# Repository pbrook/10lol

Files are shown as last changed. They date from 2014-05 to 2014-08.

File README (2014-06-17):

10LOL display board (10mm rgb led charlieplexed display matrix)
====

Hardware designs and firmware for a modular matrix display board.

Each module consists of an LED carrier board and a driver board.

Supply voltage is 7-20V (with onboard switching regulator).
TODO: Figure out actual power requirements, and if a single regulator can power
multiple modules.

The control board 
Modules operate autonomously,  module operates autonomously, accepting data over SPI.
The modules can be programmed with unique addresses, allowing
multiple modules on a single SPI bus.

SPI communication protocol
====

Commands are 4 bytes.  The first byte identidies the command, followed by 3
bytes of argument data (d0-d2).

On power-up the board will be in disconnected state.  A disconnect command
followed by a connect command should be used to ensure the serial interface
is coherent, and the board is in the ready state.

Command 0xe1 puts the specified board into the active state (other
previously active boards return to the ready state).

Commands <0xd0 are ignored when the board is not active.

Commands are as follows:

0x00 - 0x3f: Write pixel
 Pixels numbered left-right,then top-bottom)
  d0: red
  d1: green
  d2: blue

0x80: Page flip
 Set the framebuffer page for both display and pixel writing.
 This allows double buffered updates
  d0: Unused(0)
  d1: display page number
  d2: pixel write page number

0xa0: Initialize FORTH
 Initialize and enable the FORTH interpreter.
 The forth dictionary is stored at the end of the framebuffer.
  d0: rstack size (cells)
  d1: Dictionary size (in 256-byte framebuffer pages)
  d2: Unused (0)

0xa1: FORTH source
 Send one to three bytes of FORTH source code.  Null (0) characters are ignored.
  d0: First character
  d1: Second character
  d2: Third character

0xc0: Set brightness
 Sets brightness/color ballance (stored in EEPROM)
  d0: Red brightness
  d1: Green brightness
  d2: Blue brightness

0xd0: Set board address
 Modifies the board address (stored in EEPROM).
 The board will only respond to this address if the SDA pin is pulled low.
 This allows the addresses to be set without disconnecting the board.
  d0: 0xf5
  d1: 0xf0 + high address nibble
  d2: 0xf0 + low address nibble

0xe0: Connect
 Prepares the board for other commands
  d0: 0xf0
  d1: 0xf1
  d2: 0xf2

0xe1: Board select
 Only the selected board will respond to most commands.
  d0: board address (0xff to select all boards)
  d1: Unused (0)
  d2: Unused (0)

0xff: Disconnect
 Reset serial interface.
 The connect command must be sent before any other commands.
 The data bytes on this command are optional.  However sending the full
 sequence bytes ensures that the board is preoperly aligned with the
 four byte command boundary.
  d0: 0xff
  d1: 0xff
  d2: 0xff

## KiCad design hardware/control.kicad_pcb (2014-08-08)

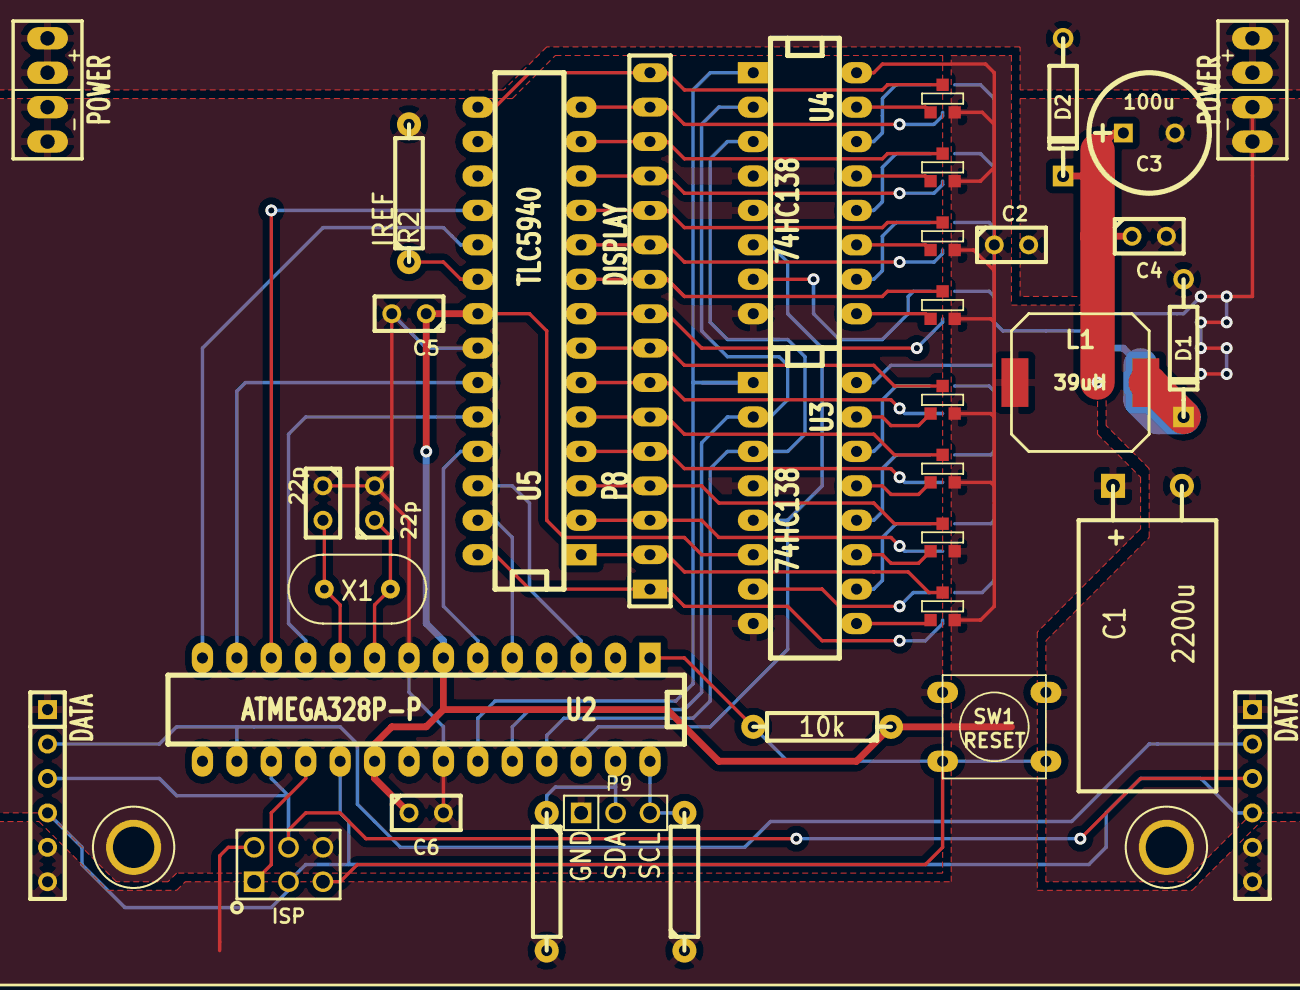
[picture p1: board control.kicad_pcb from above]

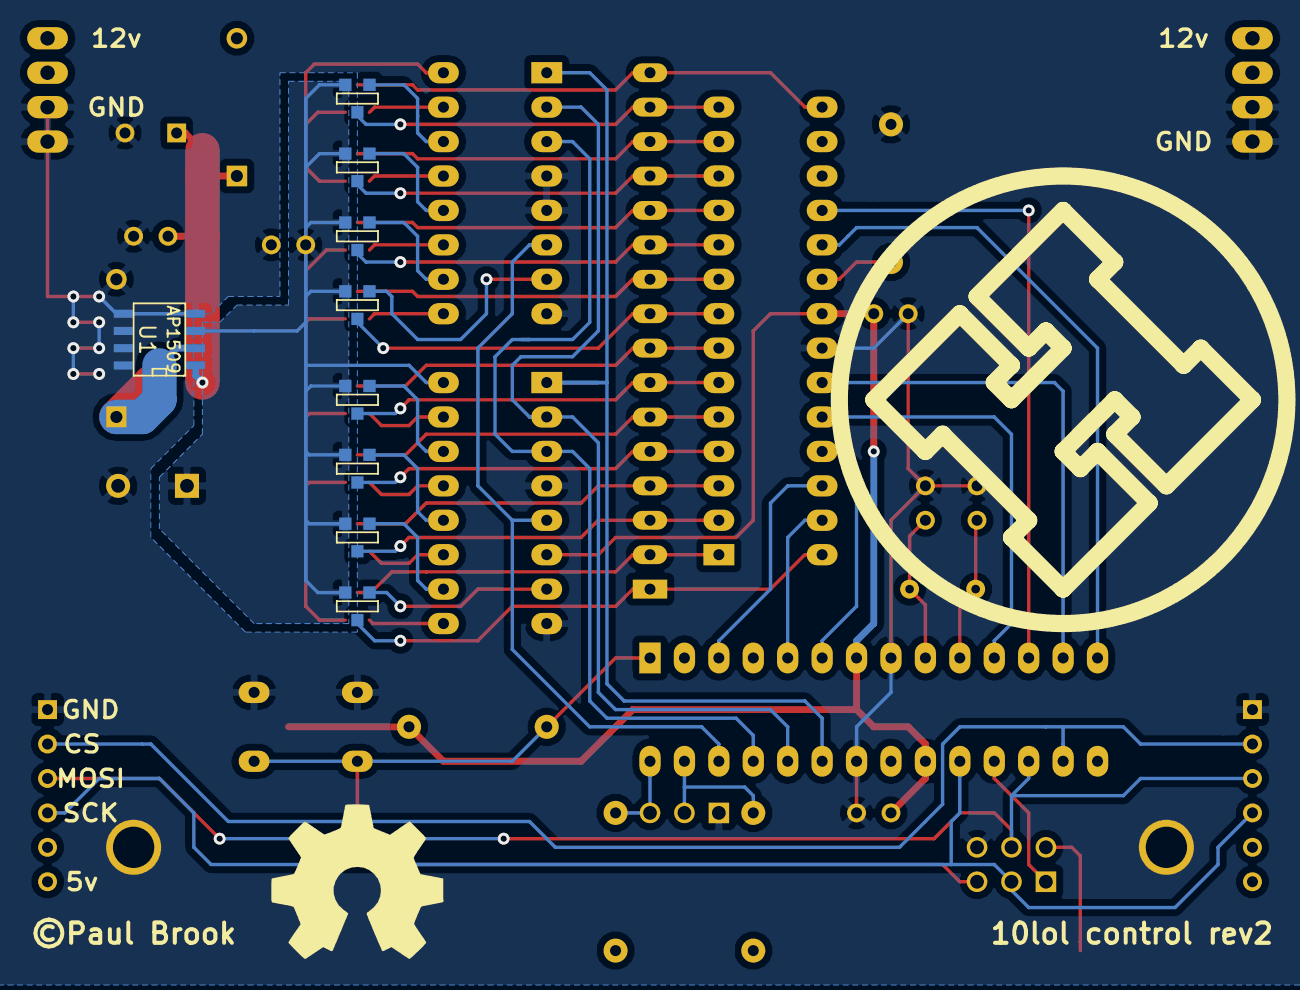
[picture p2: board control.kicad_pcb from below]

Board: 2 copper layers, 48 parts (10 on the bottom side), 58 nets.

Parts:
C1: 2200u; CPR10X20
C2, C4, C5, C6: 100n; C1
C3: 100u; C1.5V8V
C8, C9: 22p; C1
D1, D2: SR104; DO-41
HACKSPACE_LOGO: VAL**; HACKSPACE_LOGO
L1: 39uH; self_cms_we-tpc_XL
P1, P2: POWER; power2
P3, P4: DATA; SIL-6
P5: ISP; isp
P6, P7: CONN_1; HOLE3
P8: DISPLAY; SIL-16-ELL
P9: I2C; PIN_ARRAY_3X1
Q1, Q2, Q3, Q4, Q5, Q6, Q7, Q8, Q9, Q10, Q11, Q12, Q13, Q14, Q15, Q16: NX2301P; SOT23GDS_NP
R1: 10k; R4-LARGE_PADS
R2: IREF; R4-LARGE_PADS
R3: SDA; R4-LARGE_PADS
R4: SCL; R4-LARGE_PADS
SW1: RESET; SW_PUSH_SMALL
U1: AP1509; SO8E
U2: ATMEGA328P-P; DIP-28__300_ELL
U3, U4: 74HC138; DIP-16__300_ELL
U5: TLC5940; DIP-28__300_ELL
X1: 16MHz; Crystal

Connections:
/5v: C1.1, C2.1, C5.1, C6.1, L1.1, P3.5, P3.6, P4.5, P4.6, P5.2, Q1.S, Q2.S, Q3.S, Q4.S, Q5.S, Q6.S, Q7.S, Q8.S, Q9.S, Q10.S, Q11.S, Q12.S, Q13.S, Q14.S, Q15.S, Q16.S, R1.1, R3.2, R4.1, U1.3, U2.7, U2.20, U3.6, U3.16, U4.16, U5.21
/12v: C3.1, C4.1, D2.2, U1.1
/A: P8.1, Q1.D, U5.28
/A0: U2.23, U3.1, U4.1
/A1: U2.24, U3.2, U4.2
/A2: U2.25, U3.3, U4.3
/A3: U2.26, U3.5, U4.6
/Ai: Q1.G, U3.7
/B: P8.2, Q2.D, U5.1
/BLANK: U2.13, U5.23
/Bi: Q2.G, U3.9
/C: P8.3, Q3.D, U5.2
/CS: P3.2, P4.2, U2.16
/Ci: Q3.G, U3.10
/D: P8.4, Q4.D, U5.3
/DCPRG: U2.14, U5.19
/Di: Q4.G, U3.11
/E: P8.5, Q5.D, U5.4
/Ei: Q5.G, U3.12
/F: P8.6, Q6.D, U5.5
/Fi: Q6.G, U3.13
/G: P8.7, Q7.D, U5.6
/GND: C1.2, C2.2, C3.2, C4.2, C5.2, C6.2, C8.2, C9.1, D1.1, P1.1, P2.1, P3.1, P4.1, P5.6, P6.1, P7.1, P9.1, R2.2, SW1.1, U1.4, U1.5, U1.6, U1.7, U1.8, U2.8, U2.22, U3.4, U3.8, U4.4, U4.5, U4.8, U5.22
/GSCLK: U2.12, U5.18
/Gi: Q7.G, U3.14
/H: P8.8, Q8.D, U5.7
/Hi: Q8.G, U3.15
/IREF: R2.1, U5.20
/J: P8.9, Q9.D, U5.8
/Ji: Q9.G, U4.7
/K: P8.10, Q10.D, U5.9
/Ki: Q10.G, U4.9
/M: P8.11, Q11.D, U5.10
/MISO: P5.1, U2.18
/MOSI: P3.3, P4.3, P5.4, U2.17
/Mi: Q11.G, U4.10
/N: P8.12, Q12.D, U5.11
/Ni: Q12.G, U4.11
/P: P8.13, Q13.D, U5.12
/Pi: Q13.G, U4.12
/Q: P8.14, Q14.D, U5.13
/Qi: Q14.G, U4.13
/R: P8.15, Q15.D, U5.14
/RESET: P5.5, R1.2, SW1.2, U2.1
/Ri: Q15.G, U4.14
/S: P8.16, Q16.D, U5.15
/SCK: P3.4, P4.4, P5.3, U2.19
/SCL: P9.3, R4.2, U2.28
/SCLK: U2.6, U5.25
/SDA: P9.2, R3.1, U2.27
/SIN: U2.3, U5.26
/Si: Q16.G, U4.15
/VPRG: U2.5, U5.27
/XLAT: U2.11, U5.24
/out: D1.2, L1.2, U1.2
/raw: D2.1, P1.2, P2.2
unnamed: C9.2, U2.10, X1.1
unnamed: C8.1, U2.9, X1.2

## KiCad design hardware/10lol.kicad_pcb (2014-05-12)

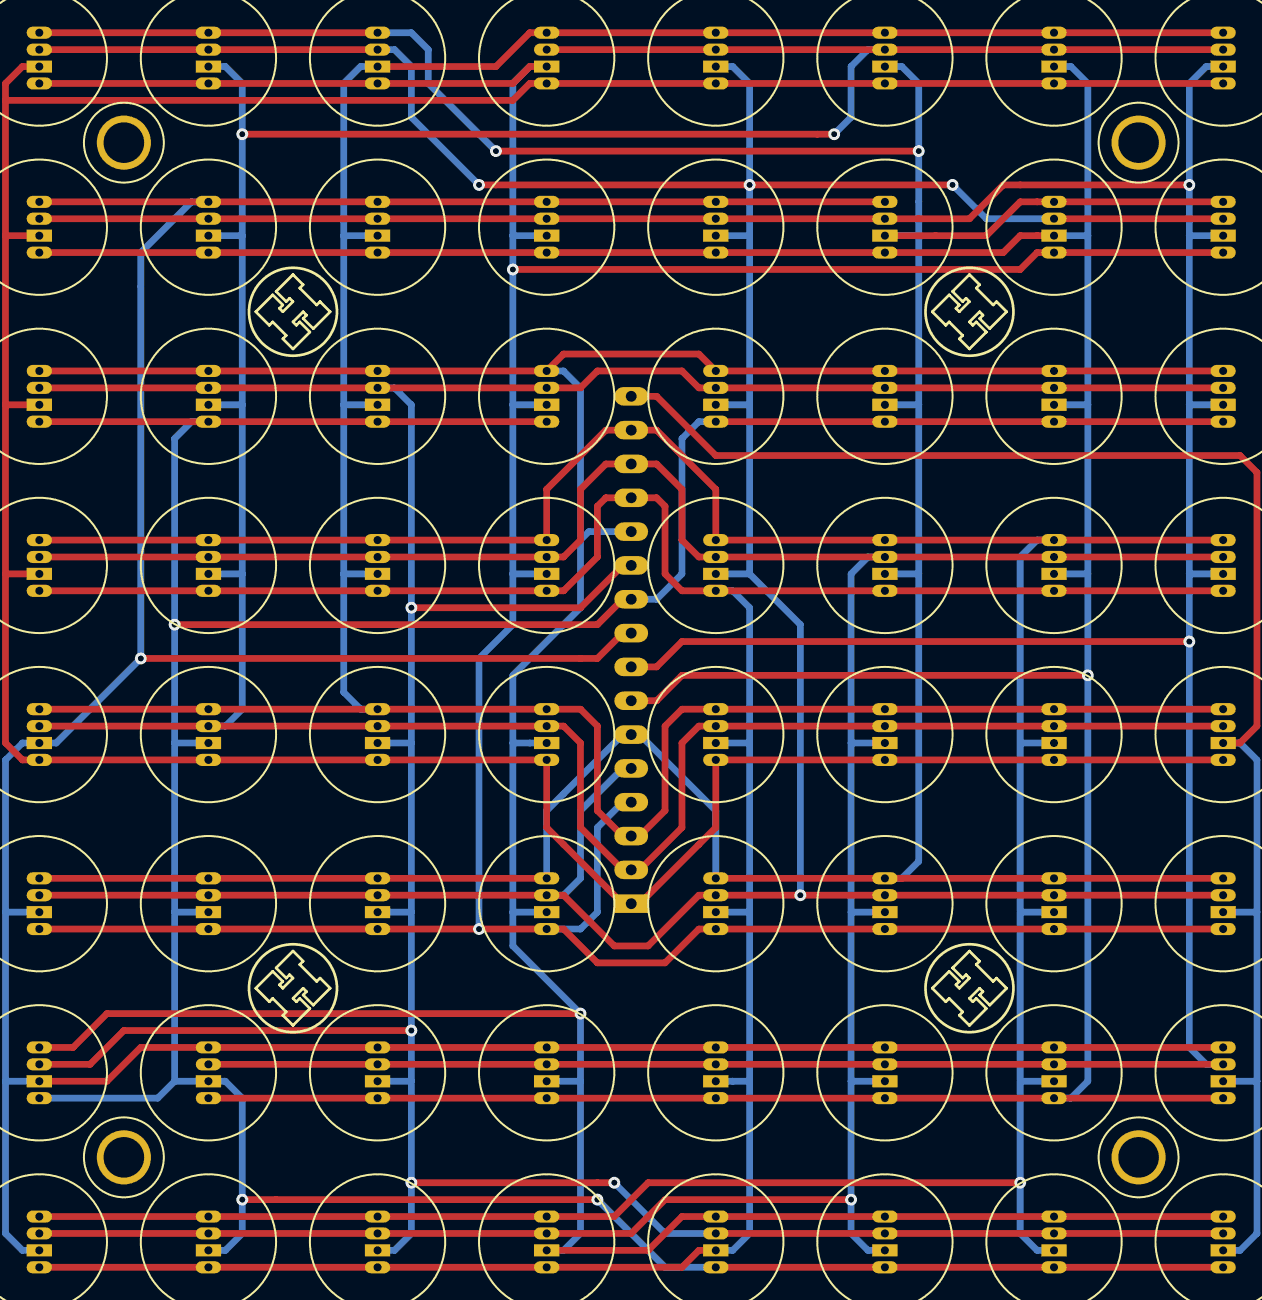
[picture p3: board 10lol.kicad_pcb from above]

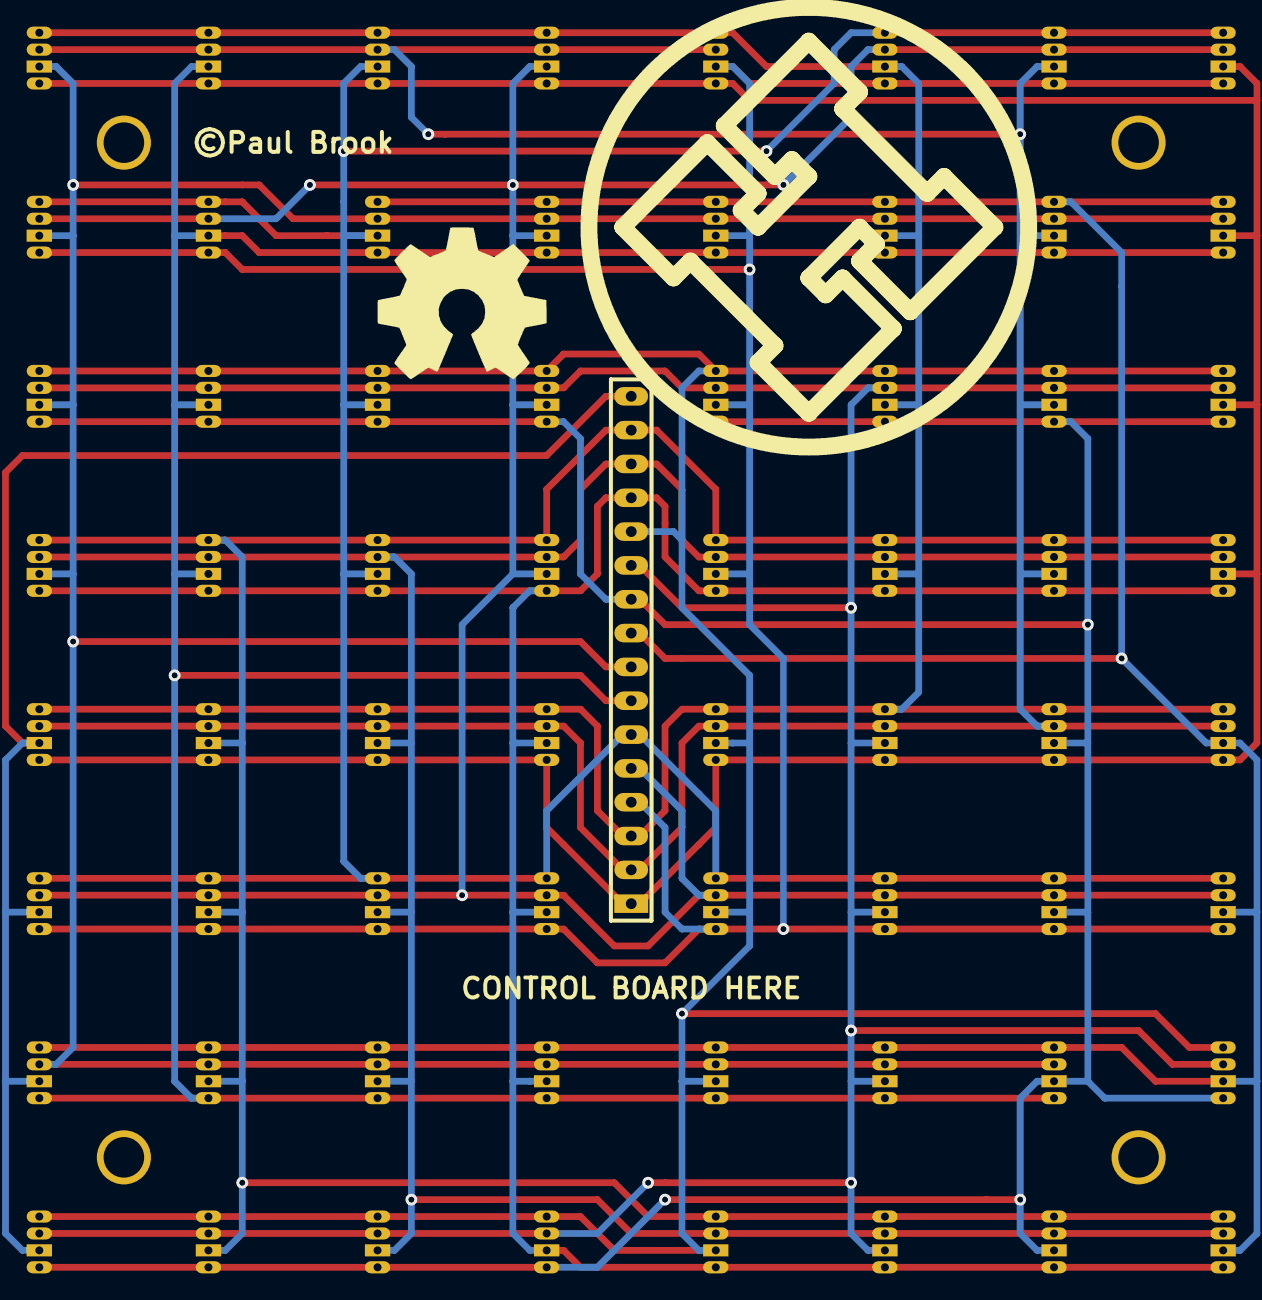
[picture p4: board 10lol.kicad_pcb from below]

Board: 2 copper layers, 74 parts (2 on the bottom side), 16 nets.

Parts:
D1, D2, D3, D4, D5, D6, D7, D8, D9, D10, D11, D12, D13, D14, D15, D16, D17, D18, D19, D20, D21, D22, D23, D24, D25, D26, D27, D28, D29, D30, D31, D32, D33, D34, D35, D36, D37, D38, D39, D40, D41, D42, D43, D44, D45, D46, D47, D48, D49, D50, D51, D52, D53, D54, D55, D56, D57, D58, D59, D60, D61, D62, D63, D64: RGBLED; RGB_LED_10_S
HACKSPACE_LOGO: VAL**; HACKSPACE_LOGO
LOGO_SMALL1: LOGO_S1; LOGO_SMALL
LOGO_SMALL2: LOGO_S2; LOGO_SMALL
LOGO_SMALL3: LOGO_S3; LOGO_SMALL
LOGO_SMALL4: LOGO_S4; LOGO_SMALL
P1: CONN_16; SIL-16-ELL
P2, P3, P4, P5: CONN_1; HOLE3

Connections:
/A: D1.2, D2.2, D3.2, D4.2, D5.1, D13.1, D21.1, D25.1, D29.1, D33.1, D37.1, D41.1, D45.1, D49.1, D53.1, D57.1, D61.1, P1.1
/B: D5.3, D9.2, D10.2, D11.2, D12.2, D13.3, D21.3, D25.3, D29.3, D33.3, D37.3, D41.3, D45.3, D49.3, D53.3, D57.3, D61.3, P1.2
/C: D5.4, D13.4, D17.2, D18.2, D19.2, D20.2, D21.4, D25.4, D29.4, D33.4, D37.4, D41.4, D45.4, D49.4, D53.4, D57.4, D61.4, P1.3
/D: D1.1, D6.1, D9.1, D14.1, D17.1, D22.1, D25.2, D26.2, D27.2, D28.2, D30.1, D38.1, D46.1, D50.1, D54.1, D58.1, D62.1, P1.4
/E: D1.3, D6.3, D9.3, D14.3, D17.3, D22.3, D30.3, D33.2, D34.2, D35.2, D36.2, D38.3, D46.3, D50.3, D54.3, D58.3, D62.3, P1.5
/F: D1.4, D6.4, D9.4, D14.4, D17.4, D22.4, D30.4, D38.4, D41.2, D42.2, D43.2, D44.2, D46.4, D50.4, D54.4, D58.4, D62.4, P1.6
/G: D2.1, D10.1, D15.1, D18.1, D23.1, D26.1, D31.1, D34.1, D39.1, D42.1, D47.1, D49.2, D50.2, D51.2, D52.2, D55.1, D63.1, P1.7
/H: D2.3, D10.3, D15.3, D18.3, D23.3, D26.3, D31.3, D34.3, D39.3, D42.3, D47.3, D55.3, D57.2, D58.2, D59.2, D60.2, D63.3, P1.8
/J: D2.4, D5.2, D6.2, D7.2, D8.2, D10.4, D15.4, D18.4, D23.4, D26.4, D31.4, D34.4, D39.4, D42.4, D47.4, D55.4, D63.4, P1.9
/K: D3.1, D7.1, D11.1, D13.2, D14.2, D15.2, D16.2, D19.1, D27.1, D35.1, D40.1, D43.1, D48.1, D51.1, D56.1, D59.1, D64.1, P1.10
/M: D3.3, D7.3, D11.3, D19.3, D21.2, D22.2, D23.2, D24.2, D27.3, D35.3, D40.3, D43.3, D48.3, D51.3, D56.3, D59.3, D64.3, P1.11
/N: D3.4, D7.4, D11.4, D19.4, D27.4, D29.2, D30.2, D31.2, D32.2, D35.4, D40.4, D43.4, D48.4, D51.4, D56.4, D59.4, D64.4, P1.12
/P: D4.1, D8.1, D12.1, D16.1, D20.1, D24.1, D28.1, D32.1, D36.1, D37.2, D38.2, D39.2, D40.2, D44.1, D52.1, D60.1, P1.13
/Q: D4.3, D8.3, D12.3, D16.3, D20.3, D24.3, D28.3, D32.3, D36.3, D44.3, D45.2, D46.2, D47.2, D48.2, D52.3, D60.3, P1.14
/R: D4.4, D8.4, D12.4, D16.4, D20.4, D24.4, D28.4, D32.4, D36.4, D44.4, D52.4, D53.2, D54.2, D55.2, D56.2, D60.4, P1.15
/S: D61.2, D62.2, D63.2, D64.2, P1.16

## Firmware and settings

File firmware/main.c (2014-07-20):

#define F_CPU 16000000ul

#include <stdint.h>

#include <avr/io.h>
#include <avr/sleep.h>
#include <avr/interrupt.h>
#include <avr/pgmspace.h>
#include <avr/cpufunc.h>
#include <avr/eeprom.h>
#include <util/delay.h>
#include <stdbool.h>
#ifdef ENABLE_FORTH
#include <forth.h>
#endif

#define FIFO_SIZE 64

#define NUM_FRAMES 6

#define NUM_PIXELS (8*8*3)

volatile uint8_t framebuffer[16 * 16 * NUM_FRAMES];

static uint8_t write_frame;
static volatile uint8_t *write_framebuffer;

static uint8_t display_frame;
static volatile uint8_t *display_framebuffer;

volatile uint8_t next_anode;

volatile uint8_t ticks;

static bool address_latch;

#define FIFO_MASK (FIFO_SIZE - 1)
#if (FIFO_SIZE & FIFO_MASK) != 0
#error
#endif
volatile uint8_t fifo[FIFO_SIZE];

volatile uint8_t fifo_head;
static uint8_t fifo_tail;

// Keep track of whether we have any nonzero pixels
volatile uint8_t data_active;

#define SET_XLAT() PORTD |= _BV(5)
#define CLEAR_XLAT() PORTD &= ~_BV(5)

#define SET_BLANK() PORTD |= _BV(7)
#define CLEAR_BLANK() PORTD &= ~_BV(7)

#define SET_VPRG() PORTD |= _BV(3)
#define CLEAR_VPRG() PORTD &= ~_BV(3)

#define SET_DCPRG() PORTB |= _BV(0);
#define CLEAR_DCPRG() PORTB &= ~_BV(0);

// This table translates from an 8x8x3 grid to the
// 16x16 anode/cathode matrix used by the framebuffer
const uint8_t pixel_map[NUM_PIXELS] PROGMEM = {
#define PIXEL(a, k) ((15 - (k)) | ((a) << 4))
#include "board.h"
};

static void
init_unused(void)
{
  // Enable pullups on unused pins
  // Not connected
  PORTB |= _BV(1);
  PORTD |= _BV(2);

  // Turn of unused peripherals
  PRR = _BV(PRTWI) | _BV(PRTIM2) | _BV(PRADC);
  ACSR = _BV(ACD);
}

static void
init_i2c(void)
{
  // We do not currently use I2C.
  // However we do use the SDA pin for address programming
  // Enable pullup and SDA and SCL
  PORTC |= _BV(4) | _BV(5);
}

static void
init_spi_slave(void)
{
  // Mode3, slave mode, MSB first, enable interrupt
  SPCR = _BV(SPIE) | _BV(SPE) | _BV(CPOL) | _BV(CPHA);

  // Enable pullups on SS, MOSI, MISO, SCK
  PORTB |= _BV(2) | _BV(3) | _BV(4) | _BV(5);
}

static void
init_spi_master(void)
{
  // Configure UART in SPI master mode, clk/2, mode0, MSB first
  UCSR0C = _BV(UMSEL01) | _BV(UMSEL00);
  UBRR0 = 0;
  UCSR0B = _BV(TXEN0);

  // Enable clock and data pins
  DDRD |= _BV(1) | _BV(4);
  // Enable pullup on input
  PORTD |= _BV(0);
}

// 2kHz refresh timer
static void
init_timer(void)
{
  // CTC mode
  TCNT1 = 0;
  OCR1A = 8000; // 8000 cycles = 500us = 2Khz
  TCCR1A = 0;
  TCCR1B = _BV(WGM12) | _BV(CS10);
  // Enable OCA interrupt
  TIMSK1 = _BV(OCIE1A);
}

static void
init_gsclk(void)
{
  // CTC mode, toggle OC0A
  TCCR0A = _BV(COM0A0) | _BV(WGM01);
  TCCR0B = 0;
  TCNT0 = 0;
  // 570kHz output clock.  Combined with a 2kHz row mux this gives a maximum
  // PWM value of 0xff, plus a bit of extra delay for latching in new data.
  OCR0A = 14;
  // Enable OC0A output
  DDRD |= _BV(6);
}

static inline void
enable_gsclk(void)
{
  TCCR0B = _BV(CS00);
}

static inline void
disable_gsclk(void)
{
  TCCR0B = 0;
  TCNT0 = 0;
  // Make sure output line is low
  _NOP();
  if (PINB & _BV(6)) {
      TCCR0B |= _BV(FOC0A);
  }
}

static uint8_t eeprom_address EEMEM;
static uint8_t eeprom_dc_r EEMEM;
static uint8_t eeprom_dc_g EEMEM;
static uint8_t eeprom_dc_b EEMEM;

static uint8_t my_address;

static inline void
set_pixel(uint8_t n, uint8_t val)
{
  uint8_t pos;
  pos = pgm_read_byte(&pixel_map[n]);
  write_framebuffer[pos] = val;
}

#ifdef ENABLE_FORTH
static uint8_t
get_pixel(uint8_t n)
{
  uint8_t pos;
  pos = pgm_read_byte(&pixel_map[n]);
  return write_framebuffer[pos];
}
#endif

static volatile uint8_t fb_offset;
static volatile bool sending_frame;
static volatile uint8_t dc_bytes;
static volatile bool dc_changed;

static uint8_t dc[12];

#ifdef ENABLE_FORTH
void
dump_val(uint8_t val)
{
  static uint8_t pos;
  uint8_t mask;

  mask = 0x80;
  while (mask) {
      if (mask & val)
	set_pixel(pos, 0xff);
      pos += 3;
      mask >>= 1;
  }
  if (pos >= 64 * 3)
    pos = 0;
}

/* Forth support:  */
static void
f_set_pixel(void)
{
  cell pos = F_POP();
  cell color = F_POP();
  if (pos >= 64 * 3)
    return;
  set_pixel(pos, color);
  data_active = 0xff;
}

static void
f_get_pixel(void)
{
  cell pos = F_POP();
  cell color;
  if (pos >= 64 * 3)
    color = 0;
  else
    color = get_pixel(pos);
  F_PUSH(color);
}

static cell tick;

static void
set_tick(void)
{
  tick = F_POP();
}

#define APP_WORDS W("pixel!", f_set_pixel) W("pixel@", f_get_pixel) W("set-tick", set_tick)
#include <forth-words.h>

// Return next character, or -1 if no characters avaialble
int
f_getchar(void)
{
  return -1;
}

void f_putchar(char c)
{
}

void
f_bye(void)
{
}
#endif

static void
maybe_suspend(void)
{
  uint8_t n;
  cli();
  n = (fifo_head - fifo_tail) & FIFO_MASK;
  if (n < 4 && !sending_frame) {
      sleep_enable();
      set_sleep_mode(SLEEP_MODE_IDLE);
      sei();
      sleep_cpu();
      sleep_disable();

  }
  sei();
}

static void
send_data(void)
{
  uint8_t tmp;

  if ((UCSR0A & _BV(UDRE0)) == 0)
    return;

  //  All data is send MSB first
  if (dc_bytes) {
      // Dot correction data
      dc_bytes--;
      UDR0 = dc[dc_bytes];
      if (dc_bytes == 0) {
	  // Wait for the transmit to complete
	  _delay_us(20);
	  // Latch data into register
	  SET_XLAT();
	  CLEAR_XLAT();
	  SET_DCPRG();
	  CLEAR_VPRG();
      }
  } else if (sending_frame) {
      // PWM data
      // The count registers are 12 bits, so a pair of values expand to 
      // 3 bytes of data.  We can not submit all this immediately, but the USART
      // double buffering means we probably only stall for 16 cycles and it is
      // not worth trying to be clever.
      tmp = display_framebuffer[fb_offset++];
      data_active |= tmp;
      UDR0 = tmp >> 4;
      tmp <<= 4;
      while ((UCSR0A & _BV(UDRE0)) == 0)
	/* no-op */;
      UDR0 = tmp;
      tmp = display_framebuffer[fb_offset++];
      data_active |= tmp;
      if ((fb_offset & 0xf) == 0) {
	  _delay_us(2);
	  sending_frame = false;
	  display_framebuffer = &framebuffer[(uint16_t)display_frame * 16 * 16];
      }
      while ((UCSR0A & _BV(UDRE0)) == 0)
	/* no-op */;
      UDR0 = tmp;
  } else {
#ifdef ENABLE_FORTH
      if (go_forth())
#endif
	maybe_suspend();
  }
}

static void
set_address(uint8_t address)
{
  if (address == 0xff)
    return;
  if (address_latch && (PINC & _BV(4)) != 0)
    return;
  my_address = address;
  eeprom_update_byte(&eeprom_address, address);
}

static void
set_dc(uint8_t red, uint8_t green, uint8_t blue)
{
  eeprom_update_byte(&eeprom_dc_r, red);
  eeprom_update_byte(&eeprom_dc_g, green);
  eeprom_update_byte(&eeprom_dc_b, blue);
  /* Dot correction data is only 6 bits.  */
  red >>= 2;
  green >>= 2;
  blue >>= 2;
  /* Pack data ready for transmission.  */
  dc[0] = red | (green << 6);
  dc[1] = (green >> 2) | (blue << 4);
  dc[2] = (blue >> 4) | (red << 2);
  dc[3] = green | (blue << 6);
  dc[4] = (blue >> 2) | (red << 4);
  dc[5] = (red >> 4) | (green << 2);
  dc[6] = blue | (red << 6);
  dc[7] = (red >> 2) | (green << 4);
  dc[8] = (green >> 4) | (blue << 2);
  dc[9] = red | (green << 6);
  dc[10] = (green >> 2) | (blue << 4);
  dc[11] = (blue >> 4); // last channel unused
  dc_changed = true;
}

enum
{
  SM_IDLE,
  SM_READY,
  SM_ACTIVE,
};

static void
do_data(void)
{
  uint8_t n;
  uint8_t cmd;
  uint8_t d0;
  uint8_t d1;
  uint8_t d2;
  uint8_t sm;

  sm = SM_IDLE;
  fifo_tail = 0;
  while (true) {
      n = (fifo_head - fifo_tail) & FIFO_MASK;
      if (n < 4) {
	  send_data();
	  continue;
      }
      cmd = fifo[fifo_tail];
      fifo_tail = (fifo_tail + 1) & FIFO_MASK;
      if (cmd >= 0xf0) {
	  sm = SM_IDLE;
	  continue;
      }
      if (cmd < 0xd0 && sm != SM_ACTIVE) {
	  fifo_tail = (fifo_tail + 3) & FIFO_MASK;
	  continue;
      }
      d0 = fifo[fifo_tail];
      fifo_tail = (fifo_tail + 1) & FIFO_MASK;
      d1 = fifo[fifo_tail];
      fifo_tail = (fifo_tail + 1) & FIFO_MASK;
      d2 = fifo[fifo_tail];
      fifo_tail = (fifo_tail + 1) & FIFO_MASK;
      data_active = 0xff;

      if (cmd == 0xe0) {
	  if (d0 == 0xf0 && d1 == 0xf1 && d2 == 0xf2)
	    sm = SM_READY;
	  else
	    sm = SM_IDLE;
	  continue;
      }
      if (sm == SM_IDLE)
	continue;
      if (cmd < 8 * 8) {
	  n = cmd * 3;
	  set_pixel(n, d0);
	  set_pixel(n + 1, d1);
	  set_pixel(n + 2, d2);
      } else if (cmd == 0x80u) {
	  /* Set framebuffer (page flip).  */
	  display_frame = d1 % NUM_FRAMES;
	  write_frame = d2 % NUM_FRAMES;
	  write_framebuffer = &framebuffer[(uint16_t)write_frame * 16 * 16];
#ifdef ENABLE_FORTH
      } else if (cmd == 0xa0) {
	  /* Initialize FORTH */
	  init_forth((void *)&framebuffer[16 * 16 * (NUM_FRAMES - d1)], d1 * 16 * 16, d0);
      } else if (cmd == 0xa1) {
	  /* FORTH source */
	  if (d0)
	    f_pushchar(d0);
	  if (d1)
	    f_pushchar(d1);
	  if (d2)
	    f_pushchar(d2);
#endif
      } else if (cmd == 0xc0) {
	  /* Set brightness */
	  set_dc(d0, d1, d2);
      } else if (cmd == 0xd0) {
	  /* Set address.  */
	  if (d0 == 0xf5 && d1 >= 0xf0 && d2 >= 0xf0) {
	      uint8_t new_address;
	      new_address = (d1 << 4) | (d2 & 0x0f);
	      set_address(new_address);
	  }
      } else if (cmd == 0xe1) {
	  address_latch = true;
	  if (d0 == my_address || d0 == 0xff)
	    sm = SM_ACTIVE;
	  else
	    sm = SM_READY;
      } else {
	  /* Unknown command.  */
	    sm = SM_IDLE;
      }
  }
}

#ifdef __AVR_ATmega328P__X
ISR(SPI_STC_vect, ISR_NAKED)
{
  asm (
"\n push r28"
"\n push r29"
"\n push r30"
"\n push r31"
"\n in r28, __SREG__"
"\n lds r30, fifo_head"
"\n1:"
"\n ldi r31, 0"
"\n in r29, 0x2e" // SPDR
"\n subi r30,lo8(-(fifo))"
"\n sbci r31,hi8(-(fifo))"
"\n st Z+,r29"
"\n subi r30,lo8(fifo)"
"\n andi r30, lo8(63)" // FIFO_MASK
"\n in r29, 0x2d" // SPSR
"\n sbrc r29, 7" // SPIF
"\n rjmp 1b"
"\n sts fifo_head, r29"
"\n out __SREG__, r28"
"\n pop r31"
"\n pop r30"
"\n pop r29"
"\n pop r28"
"\n reti" // Total 44 cycles
      );
}
#else
ISR(SPI_STC_vect)
{
  fifo[fifo_head] = SPDR;
  fifo_head = (fifo_head + 1) & FIFO_MASK;
}
#endif

ISR(TIMER1_COMPA_vect)
{
  static uint8_t overload;
  uint8_t prev_anode;
  ticks++;
  // Enable interrupts so we are not blocking the SPI slave interrupt.
  // The clock period is long enough that we don't have to worry about
  // nested timer interrupts
  sei();
  if (sending_frame) {
      overload = 0xff;
      next_anode = 0xff;
  }

  disable_gsclk();
  SET_BLANK();
  if (overload) {
      overload--;
      return;
  }
  prev_anode = next_anode;
  next_anode = (next_anode + 1) & 0xf;

  if (next_anode == 0) {
      // If we have a completely blank screen, then don't bother driving it.
      if (data_active == 0) {
	  next_anode = 0xff;
	  return;
      }
      data_active = 0;
  }

  if (prev_anode < 16) {
      // Select the active anode
      // The 8 outputs of each decoder are connected in reverse order
      PORTC = (PORTC & ~0xf) | (prev_anode ^ 7);
      // Latch data into the register
      SET_XLAT();
      CLEAR_XLAT();
  }
  // Delay a few us for everything to settle.
  _delay_us(5);

  if (next_anode < 16) {
      // Shift in the next set of anode data
      fb_offset = next_anode * 16;
      sending_frame = true;
      // And dot correction data if needed
      if (dc_changed) {
	  dc_bytes = 12;
	  SET_VPRG();
	  dc_changed = false;
      }
  }
  if (prev_anode < 16) {
      // Triggering the greyscale clock is timing critical, so disable interrupts
      cli();
      // Trigger the output pulse
      CLEAR_BLANK();
      enable_gsclk();
  }
}

static void
init_5940(void)
{
  init_gsclk();
  init_spi_slave();
  // Setup VPRG, XLAT, BLANK
  DDRD |= _BV(3) | _BV(5) | _BV(7);
  SET_BLANK();
  CLEAR_XLAT();
  CLEAR_VPRG();
  // Setup DCPRG
  DDRB |= _BV(0);
  CLEAR_DCPRG();
}

static void
init_eeprom()
{
  uint8_t r;
  uint8_t g;
  uint8_t b;
  uint8_t address;

  address = eeprom_read_byte(&eeprom_address);
  if (address == 0xff) {
      address = 0;
      r = 0x30;
      g = 0x45;
      b = 0x40;
  } else {
      r = eeprom_read_byte(&eeprom_dc_r);
      g = eeprom_read_byte(&eeprom_dc_g);
      b = eeprom_read_byte(&eeprom_dc_b);
  }
  set_address(address);
  set_dc(r, g, b);
}

static void
init_anodes(void)
{
  /* Anode select pins.  */
  DDRC |= 0xf;
  PORTC |= 0xf;
}

int
main()
{
  /* Do this early to minimize amount of time pins are left floating.  */
  SET_BLANK();
  init_anodes();

  fifo_head = 0;
  next_anode = 0xff;
  data_active = 0xff;
  sending_frame = false;
  write_framebuffer = &framebuffer[0];
  display_framebuffer = &framebuffer[0];

  init_eeprom();
  init_unused();
  init_i2c();
  init_5940();
  init_spi_master();
  init_timer();

  sei();
  do_data();
  return 0;
}

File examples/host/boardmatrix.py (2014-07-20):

#! /usr/bin/env python3

import os

port_list = ['/dev/ttyACM0', '/dev/spidev1.0']

def SerialWriter(port):
    import serial
    return serial.Serial(port, 115200)

class SPIWriter(object):
    def __init__(self, port):
        import spidev
        if port[:11] == '/dev/spidev':
            port = port[11:]
        bus = None
        for sep in '.,:-':
            if sep in port:
                p = port.split(sep)
                bus = int(p[0])
                dev = int(p[1])
                break
        if bus is None:
            if port == '':
                bus = 1
            else:
                bus = int(port)
            dev = 0
        spi = spidev.SpiDev(bus, dev)
        spi.max_speed_hz = 2000000
        spi.mode = 3
        spi.lsbfirst = False
        spi.cshigh = False
        spi.bits_per_word = 8
        self.spi = spi
    def write(self, b):
        self.spi.writebytes(b)

def find_port(l):
    for p in l:
        if os.access(p, os.R_OK | os.W_OK):
            return p
    raise Exception("Unable to find suitable port")

class BoardMatrix(object):
    def __init__(self, port, xy):
        if port is None:
            port = find_port(port_list)
        if 'spi' in port:
            self.ser = SPIWriter(port)
        else:
            self.ser = SerialWriter(port)
        self.current_board = None
        self.board_x = xy[0]
        self.board_y = xy[1]

    def do_cmd(self, cmd, d0, d1, d2):
        self.ser.write(bytearray((cmd, d0, d1, d2)))

    def bus_reset(self):
        self.do_cmd(0xff, 0xff, 0xff, 0xff)
        self.do_cmd(0xe0, 0xf0, 0xf1, 0xf2)
        self.current_board = None

    def select_board(self, board):
        self.bus_reset()
        self.do_cmd(0xe1, board, 0, 0)
        self.current_board = board

    def set_brightness(self, rgb):
        self.select_board(0xff)
        self.do_cmd(0xc0, rgb[0], rgb[1], rgb[2])

    def clear(self, rgb=(0,0,0)):
        self.select_board(0xff)
        for i in range(0, 64):
            self.do_cmd(i, 0, 0, 0)

    def set_pixel(self, xy, rgb):
        board = xy[0] >> 3
        pos = (xy[0] & 7) + (xy[1] * 8)
        if board != self.current_board:
            self.select_board(board)
        self.do_cmd(pos, rgb[0], rgb[1], rgb[2])

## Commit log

2014-04-23 Production hardware
    [10lol.kicad_pcb, 10lol.sch, rofled.kicad_pcb]
2014-04-28 Assembly interrupt handle
2014-05-03 Per board and global page flip.
    [main.c]
2014-05-05 Add test LED config.
2014-05-12 Split out control board. Simplify LED board.
    [10lol.kicad_pcb, 10lol.sch, control.sch]
2014-05-12 Create control board PCB. Finish LED board layout.
    [10lol.kicad_pcb, control.kicad_pcb, control.sch]
2014-05-12 Remove stray solder mask region
    [10lol.kicad_pcb]
2014-05-25 Use driver chips
2014-06-23 Final hardware tweaks.
    [control.kicad_pcb]
2014-07-08 Serial tweaks
    Process incoming data first. Reset link on invalid command.
    [main.c]
2014-07-17 Fix race condition in sleep code
    [main.c]
2014-07-20 Native SPI support
2014-07-20 Fix serial driver
2014-08-08 PCB fixes.
    Tweak power plane. Move mounting holes. Fix soldermask on power
    connector.
    [control.kicad_pcb]
2014-08-08 SMD inductor
    [control.kicad_pcb]

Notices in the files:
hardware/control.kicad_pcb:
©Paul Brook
